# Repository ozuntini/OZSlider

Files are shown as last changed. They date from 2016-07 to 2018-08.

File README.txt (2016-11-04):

Jun 26 2016
Projet de création d'un slider pour timelapse.
Create your own timelapse slider.

Création d'une application de déplacement du chariot via un moteur pas à pas et déclenchement de l'appareil photo.
Move a camera with stepper motor and make picture.
Arduino Uno, LCD KeypadShield SainSmart.

Thanks to Rob Taylor http://tutsplus.com/authors/rob-taylor
http://computers.tutsplus.com/tutorials/motion-control-with-arduino-motorising-a-camera-slider--cms-21539

LCD Keypad
Commande du LCD : LiquidCrystal lcd(8, 9, 4, 5, 6, 7) - 10 = backlight control
Pin : 13, 12, 11, 3, 2, 1, 0 (disponibles)
Lecture des boutons : analogRead(A0) - right= 0, up = 143, down = 328, left = 504, select = 741
Pin : Reset, 3.3v, 5v, GND, GND, Vin, A1, A2, A3, A4, A5

Utilisation : 13 = Shutter, 12 = Direction, 11 = Step, 2 = Sleep

Pololu 8825
https://www.pololu.com/product/2133

Tools
Genreral Wiring.fzz : use http://fritzing.org/home/
Modules.graphml	: use https://www.yworks.com/products/yed
Slider.xmind : use http://www.xmind.net/
Slider-Stepper-Shutter.tci : use http://b.urbani.free.fr/pagetci/tci.htm "only Windows sorry !"

Documentations
Guide de l'utilisateur.md
Guide construction.md (in progress)

Motion
Stepper motor NEMA17
GT2 Belt
GT2 Pulley 20 tooth
Flat Pulley
Slider Neewer 20"/50cm Extendable to 40"/100cm Track Dolly Rail Slider

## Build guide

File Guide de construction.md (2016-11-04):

# Guide de construction

## Pilotage du moteur pas à pas

### Carte Pololu 8825
La carte Pololu vue de dessus.

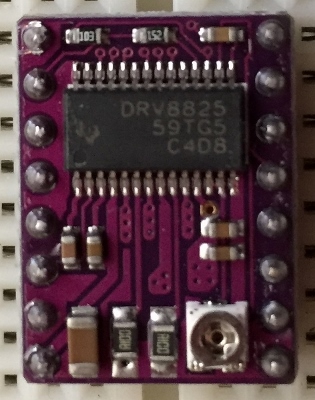
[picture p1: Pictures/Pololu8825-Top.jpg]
Pololu8825-Top


La carte Pololu vue de dessous avec les indications de correspondance des broches.

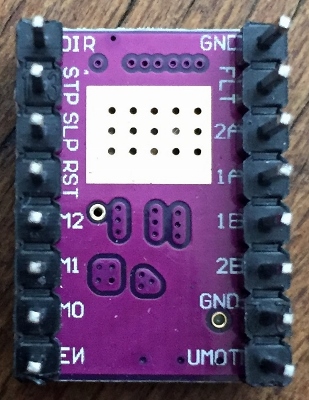
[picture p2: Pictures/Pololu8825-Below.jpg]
Pololu8825-Below


Schéma de branchement de la carte.

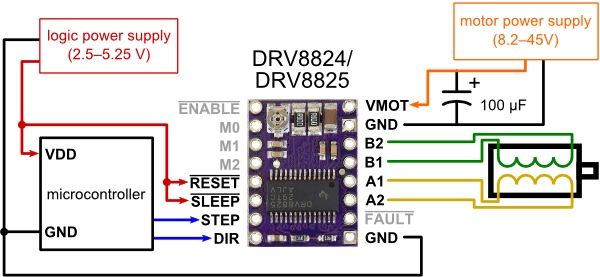
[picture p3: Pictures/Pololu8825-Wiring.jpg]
Pololu8825-Wiring


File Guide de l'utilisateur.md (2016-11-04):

#OZ-Slider version 1.0
#Guide de l'utilisateur
--
## Installation du matériel
### Connexion des modules
Trois modules composent le Slider, l'alimentation, le boitier de commande et le Slider.

* Connecter l'alimentation au Slider.

* Connecter le boitier de commande au Slider.

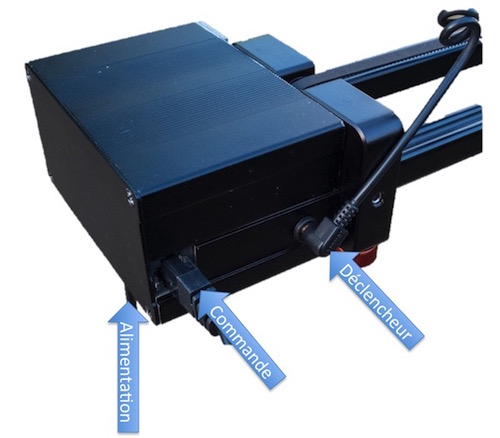
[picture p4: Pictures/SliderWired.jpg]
SliderWired


* Mettre sous tension l'ensemble depuis le boitier d'alimentation.

Le boitier de commande affiche un message de bienvenue.

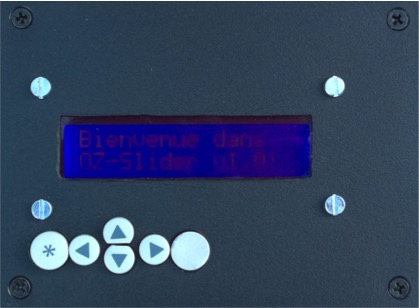
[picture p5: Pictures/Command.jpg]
Command


## Configuration du cycle
Une fois les éléments correctement connectés et sous tension, un message de Bienvenue est affiché.

>`Bienvenue dans`
 
>`OZ-Slider v1.0!`

### Luminosité du LCD
Les touches 🔼 et 🔽 permettent de modifier la luminosité de l'affichage LCD.
Cette fonction est disponible uniquement quand le message de Bienvenue est affiché.

*️⃣ pour passer à l'étape suivante.
### Longueur de déplacement du chariot
>`Long. du mvt.  >

>680 mm

▶️ permet de passer au paramètre suivant.

Par défaut il s'agit de la valeur maximum de déplacement du chariot en mm. Il n'est pas possible de saisir une valeur supérieure à la valeur maximum.

*️⃣ pour modifier la valeur. Le curseur clignote sur le premier digit.

▶️ ou ◀️ pour changer de digit.

🔼 ou 🔽 pour changer la valeur du digit.

*️⃣ pour valider la modification.
### Durée du cycle
>`< Long. cycle >`

>`60 min`

◀️ permet de revenir au paramètre précédent.

▶️ permet de passer au paramètre suivant.

Durée en minute du cycle complet de prise de vues et de déplacement. Par défaut il est à 60 min. La durée maximale est de 1020 minutes soit 17h.

*️⃣ pour modifier la valeur. Le curseur clignote sur le premier digit.

▶️ ou ◀️ pour changer de digit.

🔼 ou 🔽 pour changer la valeur du digit.

*️⃣ pour valider la modification.
### Intervalle de prise de vue
>`< Intervalle   >`

>`3 s`

◀️ permet de revenir au paramètre précédent.

▶️ permet de passer au paramètre suivant.

Durée d'un cycle, déplacement plus prise de vue en seconde. Par défaut il est à 3s.

*️⃣ pour modifier la valeur. Le curseur clignote sur le premier digit.

▶️ ou ◀️ pour changer de digit.

🔼 ou 🔽 pour changer la valeur du digit.

*️⃣ pour valider la modification.
### Direction du déplacement
>`<  Direction   >`

>`Depuis le moteur`

◀️ permet de revenir au paramètre précédent.

▶️ permet de passer au paramètre suivant.

Deux choix possibles, `Depuis le moteur` ou `Vers le moteur`. Par défaut c'est le choix `Depuis le moteur` qui est actif.

*️⃣ pour modifier la valeur.

🔼 ou 🔽 pour changer la direction.

*️⃣ pour valider la modification.
### Terminer la configuration
◀️ permet de revenir au paramètre précédent.

>`< Terminer conf?`

*️⃣ pour terminer la configuration.

## Lancement du cycle
### Affichage de la configuration du cycle
Une fois la configuration validée, elle est affichée sur deux pages écrans.
>`Mvt. : 680 mm`

>`Cycle : 60 min`

🔽 pour afficher la page suivante.

>`Inter.: 3 s`

>`Depuis le moteur`

🔼 pour afficher la page précédente.

*️⃣ pour passer à l'étape suivante.
### Affichage des paramètres calculés
#### Temps de pause maximum
Le boîtier photo doit être configuré avec un temps de pause inférieur à celui indiqué. Le temps calculé tient compte du déplacement du chariot, de son amortissement et du temps de déclenchement du boitier. L'unité est la milliseconde.
>`Temps de pause `

>`2243 ms maximum`

*️⃣ pour passer à l'étape suivante.
#### Nombre de pauses
Cette valeur indique le nombre de photos qui seront réalisées pendant le cycle.
>`Nb de pauses`

>`900 pauses`

*️⃣ pour passer à l'étape suivante.
### Dernières consignes avant le lancement du cycle
#### Connecter l'appareil photo
Ne pas oublier de connecter l'appareil photo à l'aide du câble de commande.

*️⃣ pour passer à l'étape suivante.
#### Placer le chariot
Bien positionner le chariot au point de départ. **Attention !** à l'indication donnée par le module de commande.

* Côté moteur : Le chariot doit être positionné au plus prés du moteur.
* Opposé au moteur : Le chariot doit être positionné à l'opposé du moteur.

**Important !** Un mauvais positionnement peut entrainer un blocage et une surchauffe du moteur.

*️⃣ pour passer à l'étape suivante.
### Lancement du cycle ?
>`Lancement du`

>`cycle ?`

L'appuie sur *️⃣ lance le cycle de déplacement + photo.

Pendant le cycle sont affiché :

* Le nombre de photos restant à prendre.
* Le nombre de mm parcourus.

## Fin du cycle 
A la fin du cycle le message `Fin de cycle !` est affiché.
Le chariot reste maintenu pas le moteur.

L'appuie sur *️⃣ libère le chariot.

**Attention !** Si le rail n'est pas à l'horizontal le chariot peut se déplacer et provoquer la chute du matériel.

## Arrêt du cycle
Le bouton ⏺ permet à tout moment d'arrêter le cycle.

**Attention !** Les paramêtres seront perdus il faudra reprendre le cycle depuis le début.

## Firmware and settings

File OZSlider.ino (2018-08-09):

/* OZSlider.ino
   Application de déplacement d'un appareil photo sur un slider
   afin de réaliser des Time-Lapse
   Déplacement du chariot via un moteur pas à pas et déclenchement de l'appareil photo
*/
#include <LiquidCrystal.h>
LiquidCrystal lcd(8, 9, 4, 5, 6, 7);    //set LCD output pins

// Name and Version
const char nameVersion[] = "OZ-Slider v1.1";
// Debug mode
const bool serialDebug = 0;

// ------------------------------------- Define constants of connection
//define analog read pin
const int analogReadPin = 0;			//Pin A0 is only for read button value
//define backlightControl pin
const int backlightControlPin = 10;		//Pin 10 is only backlight control, if it goes low, backlight turns off!
//define sleepDrivePin
const int sleepDrivePin = 2;
//define stepper driver pin
const int stepperDrivePin = 11;
//define chariot direction pin
const int chariotDirectionPin = 12;
//define shutter trigger pin
const int shutterTriggerPin = 13;
// ------------------------------------- Define constants of motion
//define delay for damping in ms
const int dampingDelay = 500;
//define delay for shutter command in ms
const int shutterDelay = 130;
//define moving Length maximum in mm
const int movingLengthMax = 680;	//longueur maximum du déplacement à adapter en fonction du slider
//step to mm conversion factor
const int stepTommConvFactor = 40;	//x steps for 1mm
//time per steps in ms
const int timePerSteps = 7;		//time in ms for 1 step
// ------------------------------------- Define seting variables
int movingLength = movingLengthMax; //longueur du déplacement en mm
unsigned int movingDuration = 60;	//durée du cycle en min max = 1020min soit 17h
int cycleDuration = 3;				//intervalle entre deux pauses en s min = 1s max 65s
boolean directionMotor = 0;			//0 Depuis le moteur - 1 Vers le moteur
// ------------------------------------- Define calculated variables
//Nombre de pauses calculé
unsigned int shootNumber = ((movingDuration*60)/cycleDuration);
//Temps de pause max à configurer sur le boitier photo
unsigned int shutterTimeMax = ((cycleDuration * 1000) - shutterDelay - dampingDelay - ((movingLength * stepTommConvFactor * timePerSteps) / shootNumber));

//BUTTONS
//define button values
const int btnUp = 0;
const int btnDn = 1;
const int btnL = 2;
const int btnR = 3;
const int btnSel = 4;
const int btnNone = 5;

//define button-reading variables
int btnVal = 5;
int adcIn = 0;

//declare button poll function
int readLcdButtons() {			// return value of pressed button or none
	delay(200); //debounce delay, tuned experimentally. delay is fine as program shouldn't be doing anything else at this point anyway
	adcIn = analogRead(analogReadPin); //read value
	// threshold values confirmed by experimentation with button calibration sketch returning the following ADC read values:
	// right: 0, up: 141, down: 327 left: 504 select: 741

	if (adcIn > 1000) return btnNone;
	if (adcIn < 50)   return btnR;
	if (adcIn < 200)  return btnUp;
	if (adcIn < 400)  return btnDn;
	if (adcIn < 600)  return btnL;
	if (adcIn < 850)  return btnSel;

	return btnNone; //if it can't detect anything, return no button pressed
}

//Print Modify Read
//Print value $2 on $1 car. lengh
//Modify value by push button
//Return modified value
unsigned int printModifyReadValue(int pLastCar, unsigned int currentValue){		// In=Position of last car in array, value. Out=value
	int currentValueArray[5] = {0,0,0,0,0};		// 5 digit limited
	int xCar = pLastCar-1;
	unsigned int valueInter = currentValue;
	unsigned int calc=0;
	//Make array for print and modify currentValue. Warning left alignment 
	for (int i=0; i < pLastCar; i++) {
		int fact=1;
		for (int j=1; j < (pLastCar-i); j++) {
			fact=fact*10;
		}
		valueInter=valueInter-calc;
		calc=(valueInter/fact)*fact;
		currentValueArray[i]=calc/fact;
	}
	for (int i = 0; i <= xCar; i++) {
		lcd.setCursor(i, 1);
	    lcd.print(currentValueArray[i]);
	}
	lcd.setCursor(xCar, 1);
	lcd.blink();
	do{											// set value for all digit between 0 and pLastCar
		btnVal = readLcdButtons();
		switch (btnVal) {
		    case 0:			//btnUp value digit +1
		    	currentValueArray[xCar]++;
		    	if(currentValueArray[xCar]>=10){ currentValueArray[xCar]=9; }
		    	break;
		    case 1:			//btnDn value digit -1
		    	currentValueArray[xCar]--;
		    	if(currentValueArray[xCar]<0){ currentValueArray[xCar]=0; }
		    	break;
		    case 2:			//btnL position digit -1
		    	xCar--;
		    	if(xCar<0){ xCar=0; }
		    	break;
		    case 3:			//btnR position digit +1
		    	xCar++;
		    	if(xCar>=pLastCar){ xCar=pLastCar-1; }
		    	break;
		    default:
		      // do something
		      break;
		}
		lcd.setCursor(xCar, 1);
		lcd.print(currentValueArray[xCar]);
		lcd.setCursor(xCar, 1);
	} while (btnVal!=4);
	lcd.noBlink();
	// calcul a final value
	currentValue = 0;
	for (int i = 0; i < pLastCar; i++) {
		currentValue *= 10;
		currentValue += currentValueArray[i];
	}
	return currentValue;
}

void readConfig(int iConfig) {	// for each parameters readConfig
	switch (iConfig) {
	    case 0:							//Config de la gestion du mvt movingLength
	    	// display value
			lcd.setCursor(0,1);
	    	lcd.print(movingLength);
	    	// display info
	    	lcd.setCursor(4,1);
	    	lcd.print(" mm ");
	    	lcd.setCursor(8,1);
	    	lcd.print(movingLengthMax);
	    	lcd.setCursor(12,1);
	    	lcd.print(" max");
	    	// set value
	    	movingLength = int(printModifyReadValue(4,movingLength));
	    	if(movingLength > movingLengthMax){movingLength = movingLengthMax;}
			lcd.setCursor(0,1);
			lcd.print("    ");
			lcd.setCursor(0,1);
	    	lcd.print(movingLength);
	    	lcd.print(" mm");
	    	break;
	    case 1:							//Config de la duree du mvt movingDuration
	    	// display value
			lcd.setCursor(0,1);
	    	lcd.print(movingDuration);
	    	// display info
	    	lcd.setCursor(4,1);
	    	lcd.print(" min 1020max");
	    	// set value
	    	movingDuration = printModifyReadValue(4,movingDuration);
	    	if(movingDuration > 1020){movingDuration = 1020;}
			lcd.setCursor(0,1);
			lcd.print("     ");
			lcd.setCursor(0,1);
	    	lcd.print(movingDuration);
	    	break;
	    case 2:							//Config de la duree d'un cycle cycleDuration
	    	// display value
			lcd.setCursor(0,1);
	    	lcd.print(cycleDuration);
	    	// display info
	    	lcd.setCursor(5,1);
	    	lcd.print(" s     ");
	    	// set value
	    	cycleDuration = int(printModifyReadValue(4,cycleDuration));
			lcd.setCursor(0,1);
			lcd.print("    ");
			lcd.setCursor(0,1);
	    	lcd.print(cycleDuration);
	    	break;
	    case 3:							//Config de la direction du mvt, Vers le moteur ou Depuis le moteur
	    	do{
	    		lcd.setCursor(0, 1);
	    		lcd.blink();
	    		if(!directionMotor){
	    			lcd.print("Depuis le moteur");  
	    		} else {
	    			lcd.print("Vers le moteur  ");
	    		}
	    		lcd.setCursor(0,1);
				btnVal = readLcdButtons();
				if(btnVal==0 || btnVal ==1){ directionMotor = directionMotor ^ 1; }	//bascule de directionMotor
	    	} while (btnVal!=4);		//Sortie sur bouton select
	    	lcd.noBlink();
	    	break;
	    default:
	    	break;
	}
	delay(1000);
}

void config() {					// print menu and and call readConfig
	//	Define menu config
	char* menuConfigItems[] = {
		"Long. du mvt.  >", "< Long. cycle >", "< Intervalle   >", "<  Direction   >", "< Terminer conf?"};
	unsigned int valueItems[4] = {movingLength,movingDuration,cycleDuration,directionMotor};
	char* unitItems[] = {" mm", " min", " s", "", ""};
	int iMenu=0;
	while(iMenu<5){				//Modifier la limite si plus ou moins d'item au menu
		lcd.clear();
	    lcd.setCursor(0,0);
	    lcd.print(menuConfigItems[iMenu]);
	    lcd.setCursor(0,1);
	    if(iMenu<3){
	    	lcd.print(valueItems[iMenu]);
	    	lcd.print(unitItems[iMenu]);
	    } else {
	    	if(iMenu==3){
	    		if(!directionMotor){
	    			lcd.print("Depuis le moteur");
		    	} else {
		    		lcd.print("Vers le moteur  "); }
	    	} else {
	    		lcd.print("                "); }
	    }
	    do {
	    	btnVal = readLcdButtons();      //continually read the buttons...
	    } while (btnVal==5 || btnVal==0 || btnVal==1);	//on ne sort que sur btnR, btnL ou btnSel
	    switch (btnVal) {
	    	case 2:							//Left button
	    	   	iMenu--;
	    	   	if(iMenu<0){iMenu=0;}
	    	   	break;
	    	case 3:							//Right button
	    		iMenu++;
	    		if(iMenu>4){iMenu=4;}
	    	    break;
	    	case 4:							//Select button
	    		if(iMenu==4){				//End conf Menu
	    			iMenu=5;	    		    
	    		}
	    		else{
	    			readConfig (iMenu);
	    			valueItems[0] = movingLength;
	    			valueItems[1] = movingDuration;
	    			valueItems[2] = cycleDuration;
				}
	    	    break;
	    	default:
	    	    break;
	    	delay(500);
	    }
	}
}

// Display movingLength, movingDuration, cycleDuration during 10 seconds
// Display calculated shootNumber and shutterTimeMax
void page1(){
	lcd.clear();
	lcd.setCursor(0,0);
	lcd.print("Mvt. : ");
	lcd.print(movingLength);
	lcd.print(" mm     ");
	lcd.setCursor(0,1);
	lcd.print("Cycle : ");
	lcd.print(movingDuration);
	lcd.print(" min   ");
}
void page2(){
	lcd.clear();
	lcd.setCursor(0,0);
	lcd.print("Inter.: ");
	lcd.print(cycleDuration);
	lcd.print(" s     ");
	lcd.setCursor(0,1);
	if(!directionMotor){
		lcd.print("Depuis le moteur");
	} else {
		lcd.print("Vers le moteur  ");
	}
}
void displayConfig(){
	page1();
	do {
		btnVal = readLcdButtons();
		switch (btnVal) {
		    case 0:
		    	page1();
		      	break;
		    case 1:
		    	page2();
		      	break;
		    default:
		    	break;
		}
		delay(100);
	} while (btnVal!=4);
}

void backlightControl() {		//Modification de la luminosité du LCD
	int valBacllight = 4;
	do {
		analogWrite(backlightControlPin, map(valBacllight, 0, 25, 0, 255));
		btnVal = readLcdButtons();
		switch (btnVal) {
		    case 0:
		    	valBacllight++;
		    	if(valBacllight>10){ valBacllight=10; }
		      	break;
		    case 1:
		    	valBacllight--;
		    	if(valBacllight<0){ valBacllight=0; }
		      	break;
		    default:
		    	break;
		}
		delay(100);
	} while (btnVal!=4);
}

void setup() {
	if (serialDebug){
		Serial.begin(9600);
		Serial.print(nameVersion);
		Serial.println(" !");
	}
	// set pin mode
	pinMode(backlightControlPin, OUTPUT);	// set backlight pin output
	pinMode(sleepDrivePin, OUTPUT);			// set sleep motor pin output
	pinMode(stepperDrivePin, OUTPUT);		// set motor pin output
	pinMode(chariotDirectionPin, OUTPUT);	// set direction pin output
	pinMode(shutterTriggerPin, OUTPUT);		// set shutter pin output
	// set pin state
	digitalWrite(sleepDrivePin, LOW);
	digitalWrite(stepperDrivePin, LOW);
	digitalWrite(chariotDirectionPin, LOW);
	digitalWrite(shutterTriggerPin, LOW);

	lcd.begin(16, 2);               // initialise LCD lib full-screen
	lcd.setCursor(0,0);             // set cursor position
	lcd.print("Bienvenue dans");	// welcome screen
	lcd.setCursor(0,1);
	lcd.print(nameVersion);
	lcd.print(" !");
	backlightControl();				// gestion manuelle du backlight Up, Dn, Sel
}

void loop() {
	// ------------------------------------------------------ Gestion de la config
	config();						// enregistrement de la configuration du set
	// ------------------------------------------------------ Calcul des valeurs de travail et affichage 
	// Nombre de pauses calculé
	shootNumber = ((movingDuration*60)/cycleDuration);
	// Temps de pause max en ms à configurer sur le boitier photo
	shutterTimeMax = ((cycleDuration * 1000) - shutterDelay - dampingDelay - ((movingLength * stepTommConvFactor * timePerSteps) / shootNumber));
	displayConfig();					// print config and shootNumber and cycleDuration
	// Display shutterTimeMax
	lcd.clear();
	lcd.setCursor(0,0);
	lcd.print("Temps de pause  ");
	lcd.setCursor(0,1);
	lcd.print(shutterTimeMax);
	lcd.setCursor(5,1);
	lcd.print(" ms maximum     ");
	do {
		btnVal = readLcdButtons();
		delay(100);
	} while (btnVal!=4);
	// Display shutterTimeMax
	lcd.clear();
	lcd.setCursor(0,0);
	lcd.print("Nb. de pauses   ");
	lcd.setCursor(0,1);
	lcd.print(shootNumber);
	lcd.setCursor(5,1);
	lcd.print(" pauses     ");
	do {
		btnVal = readLcdButtons();
		delay(100);
	} while (btnVal!=4);
	// Connexion de l'appareil photo
	lcd.clear();
	lcd.setCursor(0,0);
	lcd.print("Connecter ");
	lcd.setCursor(0,1);
	lcd.print("l'appareil photo");
	do {
		btnVal = readLcdButtons();
		delay(100);
	} while (btnVal!=4);
	// Positionnement du chariot
	lcd.clear();
	lcd.setCursor(0,0);
	lcd.print("Placer chariot");
	lcd.setCursor(0,1);
	if(!directionMotor){
	    lcd.print("Cote moteur     ");     
	} else {
		lcd.print("Oppose au moteur");
	}
	do {
		btnVal = readLcdButtons();
		delay(100);
	} while (btnVal!=4);


	long stepsMovingLength = movingLength * stepTommConvFactor; 	// déplacement total en pas
	int stepsInterval = stepsMovingLength / shootNumber;			// nb de pas à déplacer entre deux pause

			// put config on serial port
			if (serialDebug){
				Serial.println("Config");
				Serial.print("Long. Mvt : ");
				Serial.println(movingLength);
				Serial.print("Long. du set : ");
				Serial.println(movingDuration);
				Serial.print("Temps d'un Cycle : ");
				Serial.println(cycleDuration);
				Serial.print("Direction : ");
				Serial.println(directionMotor);
			}
			//
			if (serialDebug){
				Serial.print("Nb. de pause : ");
				Serial.println(shootNumber);
				Serial.print("Temps de pause max : ");
				Serial.println(shutterTimeMax);
				Serial.print("Long. Mvt en step : ");
				Serial.println(stepsMovingLength);
				Serial.print("Intervalle en pas : ");
				Serial.println(stepsInterval);
			}
	int stepsIntervalTime = (stepsInterval * timePerSteps);				// temps de déplacement de stepsInterval en ms
			if (serialDebug){
				Serial.print("Temps de déplacement : ");
				Serial.println(stepsIntervalTime);
			}
			//

	// ------------------------------------------------------ Lancement du cycle ?
	lcd.clear();
	lcd.setCursor(0,0);
	lcd.print("Lancement du");
	lcd.setCursor(0,1);
	lcd.print("cycle ?");
	do {
		btnVal = readLcdButtons();
		delay(100);
	} while (btnVal!=4);
	// ------------------------------------------------------ Cycle de fonctionnement
	lcd.clear();
	lcd.setCursor(0,0);
	lcd.print("Cycle en cours");
	// Sens du mouvement
	digitalWrite(chariotDirectionPin, directionMotor);
	// Motor sleep mode off
	digitalWrite(sleepDrivePin, HIGH);
	// ------------------------------------------------------ Départ du Cycle
	unsigned long timeStart;
	unsigned int stepsNumber=0;
	timeStart = millis();
	// déclenchement de la première photo
			//Serial.print(" - Shutter ");
	digitalWrite(shutterTriggerPin, LOW);
	digitalWrite(shutterTriggerPin, HIGH);		// Shutter On
	delay(shutterDelay);
	digitalWrite(shutterTriggerPin, LOW);
	do{											// Attente de la fin de pause
		delay(50);
	} while ((millis() - timeStart) < (cycleDuration * 1000));
	// ------------------------------------------------------ Boucle de Cycle
	int seqCycle=0;
	do{
	    // Incrementation du cycle
	    seqCycle++;
	    // Mesure de la durée du cycle
		timeStart = millis();
			//Serial.print(seqCycle);
		// déplacement du chariot
			//Serial.println("- Move.");
		for(int steps=0; steps < stepsInterval; steps++){
			digitalWrite(stepperDrivePin, HIGH);
			delay(2);
			digitalWrite(stepperDrivePin, LOW);
		    delay(2);
		    stepsNumber++;
		}
		// amortissement
		delay(dampingDelay);
		// déclenchement de la photo
			//Serial.print(" - Shutter ");
		digitalWrite(shutterTriggerPin, LOW);
		digitalWrite(shutterTriggerPin, HIGH);		// Shutter On
		delay(shutterDelay);
		digitalWrite(shutterTriggerPin, LOW);
		// Print conditions
		lcd.setCursor(0,0);
		lcd.print(seqCycle);
		lcd.print("/");
		lcd.print(shootNumber);
		lcd.print(" Photos      ");
		lcd.setCursor(0,1);
		lcd.print(stepsNumber/stepTommConvFactor);
		lcd.print(" mm parcourus");
		// Serial.print conditions
		if (serialDebug){
			Serial.print(seqCycle);
			Serial.print("/");
			Serial.print(shootNumber);
			Serial.print(" Photos ");
			Serial.print(stepsNumber/stepTommConvFactor);
			Serial.println(" mm parcourus");
		}
		do{
		    delay(50);
		} while ((millis() - timeStart) < (cycleDuration * 1000));
		// Max steps limit
	} while (stepsNumber <= stepsMovingLength - stepsInterval);
	// ------------------------------------------------------ Fin de boucle de Cycle
	if (serialDebug){
		Serial.println("Fin de Cycle !");
		Serial.print("Nb de Cycle : ");
		Serial.println(seqCycle);
		Serial.print("Nb de pas : ");
		Serial.println(stepsNumber);
		}
	
	lcd.setCursor(0,0);
	lcd.print("Fin du cycle !  ");
	lcd.setCursor(0,1);
	lcd.print(seqCycle);
	lcd.print(" Pho. ");
	lcd.print(stepsNumber/stepTommConvFactor);
	lcd.print(" mm");
	do {
		btnVal = readLcdButtons();
		delay(100);
	} while (btnVal!=4);
	// Motor sleep mode on
	digitalWrite(sleepDrivePin, LOW);
}

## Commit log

2016-06-22 Tentative de gestion des menus et de la configuration
2016-06-23 Gestion du défilement des messages du menu de configuration. Gestion des débranchements pour chaque menu. Control du bon fonctionnement
2016-06-24 Debut du traitement de la lecture des configurations. Affichage des valeurs à modifier pour les deux premiers menus.
2016-06-24 Gestion du backlight control manuelle sur le message d'accueil Création de la fonction backlightControl Gestion de la config de directionMotor Création de la fonction blink pour signaler la validatio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
2016-06-24 Ajout de commentaires pour une meilleure visbilité quand le code est masqué
2016-06-25 Création de la fonction modifyReadValue pour lire et modifier la valeur de la config Ajout de l'init de la comm série pour vérifier le fonctionnement du prog Mémorisation des valeurs de la config Aff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
2016-06-26 Affichage des valeurs sous le menu. Mémorisation des valeurs pour reaffichage dans le parcour du menu. Déplacement des fonctions pour améliorer la lecture. Fonction appelée avant fonction appelante. 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
2016-07-01 Ajout d'information dans le README, LCD shield + remerciements. Ajout Modules.graphml pour poser la réflexion sur l'intégration de l'ensemble. Ajout de mind map de réflexion sur le projet
2016-07-02 Ajout d'information sur la carte pololu 8825 dans le readme. Images sur la pololu 8825, dessous, dessus et connexions. Schéman d'inplantation et de connectique des différents composants General Wirin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
    [General Wiring.fzz]
2016-07-03 chéma de commande du shutter et des des capteurs de fin de course.
    [General Wiring.fzz]
2016-07-05 Création de la fonction printModifyReadValue pour afficher la valeur à modifier. Phase de qualif de la config. Désactivation des Serial.print de la config.
2016-07-06 Conversion au format jpg de l'image Pololu8825-Below pour réduction du poid.
2016-07-06 Suppression du fichier suite à la conversion en jpg.
2016-07-06 Correction orthographique des commentaires
    [OZSlider.ino]
2016-07-11 Modification du shutterTime pour passage en seconde. Limitation de la valeur de movingLength à movingLengthMax. Calcul en temps réel du stepsNumber. Passage en minute du movingDuration car plus simpl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
    [General Wiring.fzz]
2016-07-12 Ecriture de la partie déplacement Attente de sélection de départ de cycle. Message de positionnement du chariot Changement du nom de la variable stepsNumber en shootNumber Cycle de fonctionnement. Dé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
2016-07-12 Mise à jour du Readme et du Wiring pour la connectique
    [General Wiring.fzz]
2016-07-13 Mise à jour des documents de travail, mindmap, block et schéma
2016-07-13 Mise à jour du document de travail, mindmap
2016-07-13 Message d'incitation à connecter l'appareil photo. Déplacement de l'attente de confirmation du lancement juste avant le cycle. Affichage pendant le cycle du nombre de photos sur la 1er ligne et du no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
2016-07-14 Ajout d'informations dans le README. Création de la doc utilisateur.
2016-07-16 CI du boitier de commande
2016-07-17 Connexion du Reset au Sleep pour éviter les pb d'alimentation +5v. Dernière vérification avant envoi à la production du CI.
2016-07-19 Modifications suite à la mise en production du CI.
2016-07-19 Création du Guide de construction, déplacement des images dans un répertoire pour améliorer l'organisation du répertoire. Chapitrage du guide de l'utilisateur.
2016-07-19 Corrections suite aux tests de fonctionnement avec le Slider
    [OZSlider.ino]
2016-07-20 Amélioration de la lisibilité du code.
2016-07-21 Modification de la partie motion
2016-07-22 Refonte de la partie motion et de la partie config.
2016-07-22 Refonte de la partie configuration. Affichage des paramètres saisis. Affichage du temps de pause maximum permis en fonction de la configuration. Refactoring du cycle de fonctionnement.
2016-07-24 Amélioration de l'affichage des informations en cours de cycle. Corrections mineures du cycle de fonctionnement. Déplacement du Motor Sleep on après l'aquitement de fin de cycle. Changement de l'unit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
    [OZSlider.ino]
2016-08-18 Modification du facteur de conversion pas/mm
2016-09-26 Ajout d'idée sur les évolutions fonctionnelles possibles. Suite au stage de Carcans.
2016-09-29 Correction avant release de la version 1.0
2016-10-02 Correction de la doc d'utilisation. Ajout du chapitre sur les branchements. Ajout d'images sur le slider et le boitier de commande.
2016-10-02 jout d'images sur le slider et le boitier de commande.
2016-11-04 Ajout d'un outil de vérification des valeurs analogiques des boutons du LCD Keypad Shield. Modification des valeurs analogiques pour qu'elles soient compatible avec les deux Shield en ma possession.
2016-11-04 Mise à jour du README.txt pour référencer les éléments mécaniques.
2016-11-04 Correction de fautes d'orthographes.
2016-11-04 Correction de mise en page
2016-11-07 Déplacement de l'application LCD_button_ADC_input dans un répertoire. Affichage version 1.1 Modification de la boucle de cycle pour terminer sur le parcour et non pas sur le nombre de photos. Le calc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
    [OZSlider.ino]
2017-05-20 config de Code pour OZSlider
2018-08-09 Création de la constante nameVersion pour avoir la version en haut du fichier sources. Création de la constante serialDebug pour valider l'affichage d'information sur la console série. Modification d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
